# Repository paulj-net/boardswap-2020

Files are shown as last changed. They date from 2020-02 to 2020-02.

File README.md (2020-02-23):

# boardswap-2020

This repo contains design files for my contribution to the 2019/2020 boardswap series.  More details on our boardswap can be found on the Boldport Club Discord Server.

A little history on the project...  I got my start in electronics building guitar effects kits.  I've always been fascinated by audio and electronics.  This little circuit was orginally going to be a variation of an Atari Punk Console (hence some of the filenames) but it ended up just being a simple little one octave keyboard with a focus on correct pitch.  The circuit is tuned for proper note steps with the pot in the middle position.  Due to the type of circuit employed the steps between keys change as you move farther from the middle position.  It's not perfect, I'd change a few of the pads to make soldering easier.  I'd also spin the pot 180 degrees and experiment with other speakers.  The particular speaker chosen has a resonant frequency that is hit fairly easily as you play the instrument.  My kids love when that happens, I see it as an area for improvement.  In any case I hope you enjoy it!

Design files were all created in KiCad.

Mouser BOM is here:
https://www.mouser.com/ProjectManager/ProjectDetail.aspx?AccessID=b0c3233f29

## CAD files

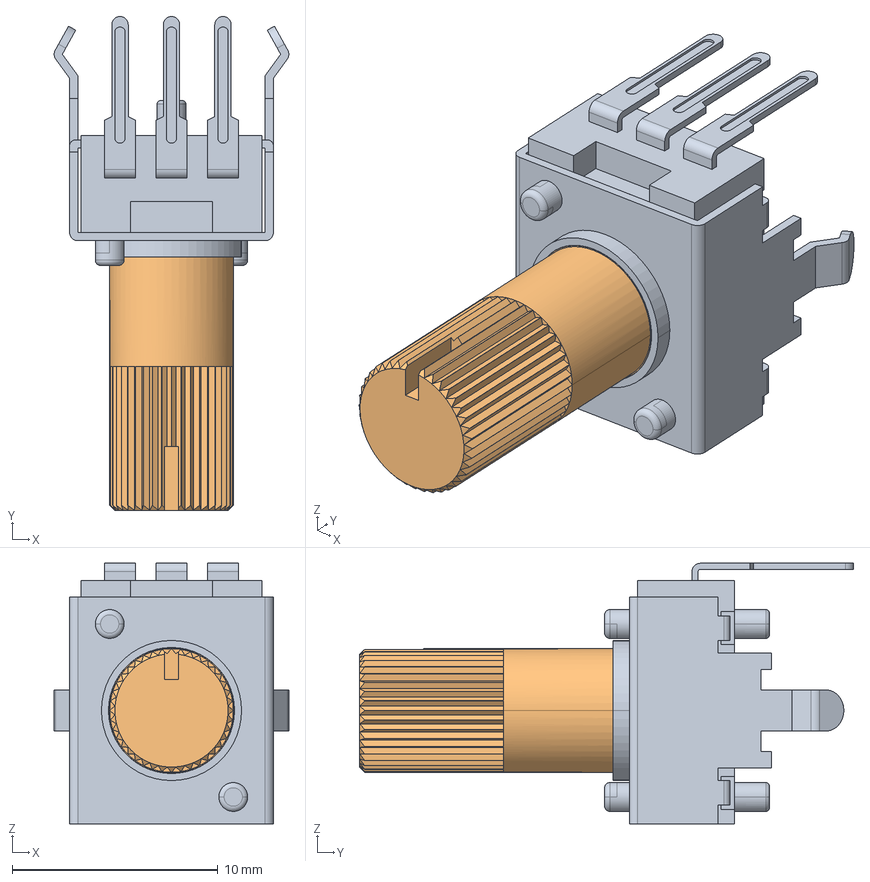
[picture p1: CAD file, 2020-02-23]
punk/parts/ptv09a-4x20u-xxxx.stp
11.4 x 24.0 x 12.7 mm

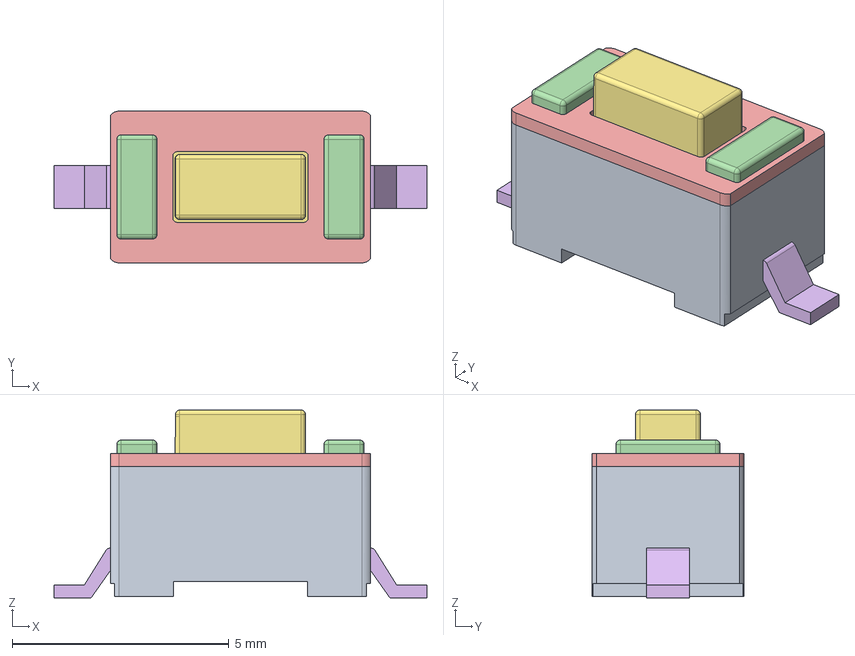
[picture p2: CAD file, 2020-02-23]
punk/parts/PTS636SM43SMTRLFS.stp
8.60 x 3.50 x 4.33 mm

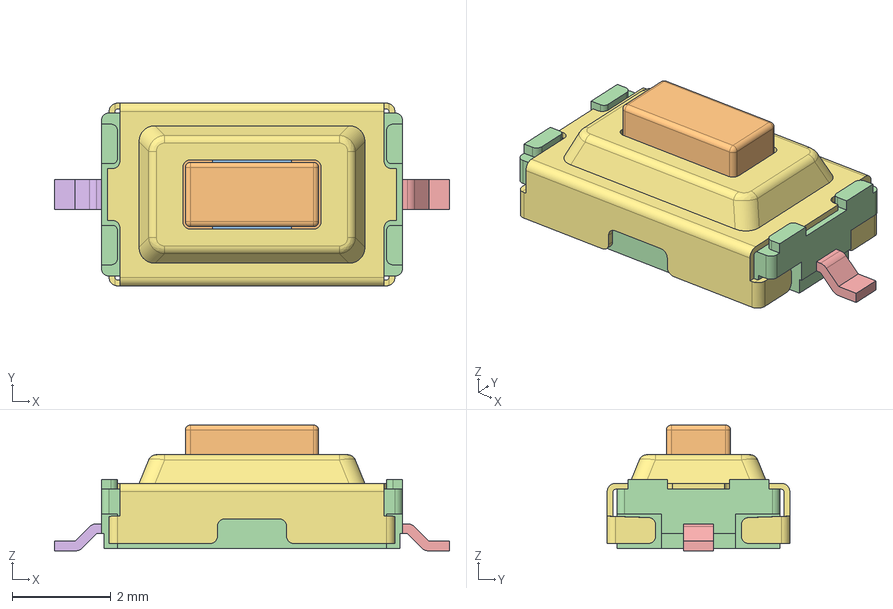
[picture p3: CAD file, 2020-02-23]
punk/parts/PTS636SM25SMTRLFS.stp
8.00 x 3.70 x 2.55 mm
MSBR-7_1
MSBR-6_1
MSBR-4_1
MSBR-3_1
MSBR-2_1
MSBR-1_1
MSBR-5-JIEDI_1

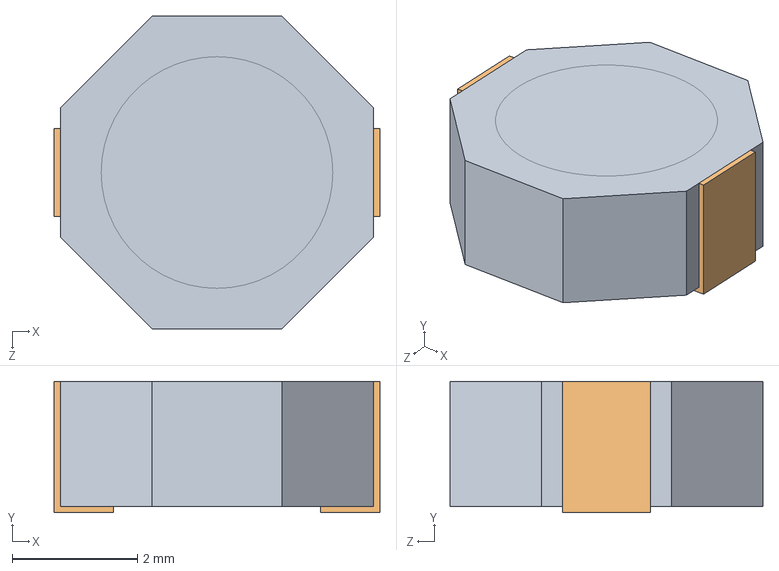
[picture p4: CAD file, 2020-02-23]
punk/parts/ltf5022-lc.step
5.20 x 2.10 x 5.00 mm
LTF5022-LC_素体
LTF5022-LC_端子 x 2

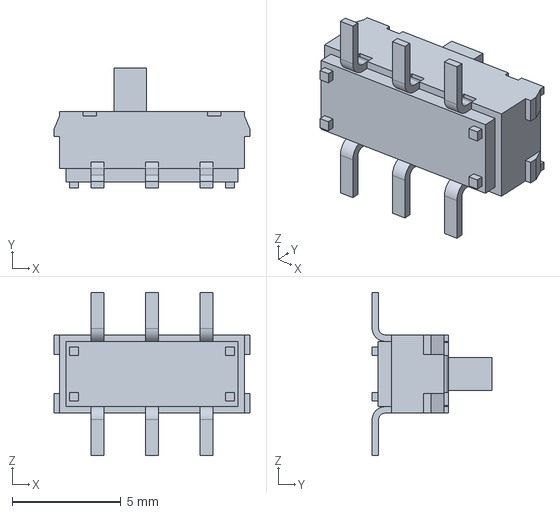
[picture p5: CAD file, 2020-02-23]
punk/parts/JS202011SCQN.stp
9.00 x 5.50 x 7.50 mm

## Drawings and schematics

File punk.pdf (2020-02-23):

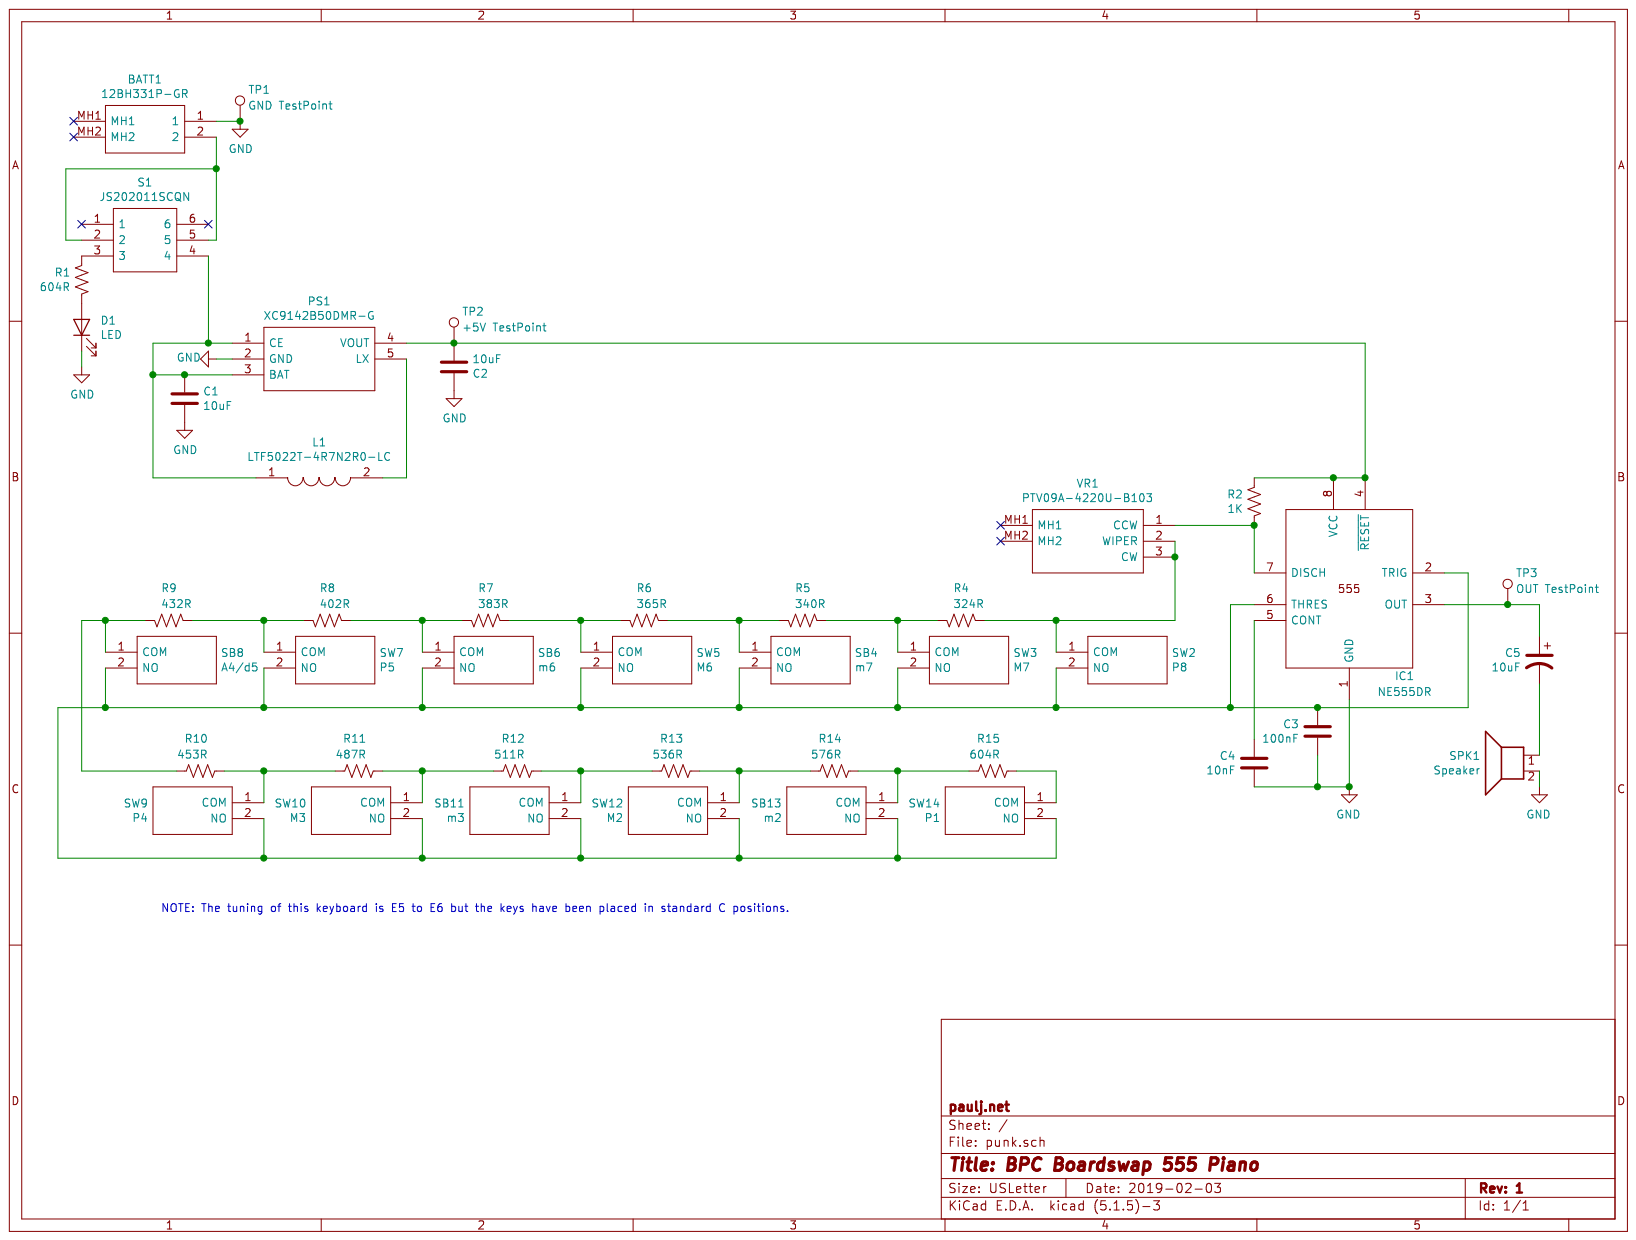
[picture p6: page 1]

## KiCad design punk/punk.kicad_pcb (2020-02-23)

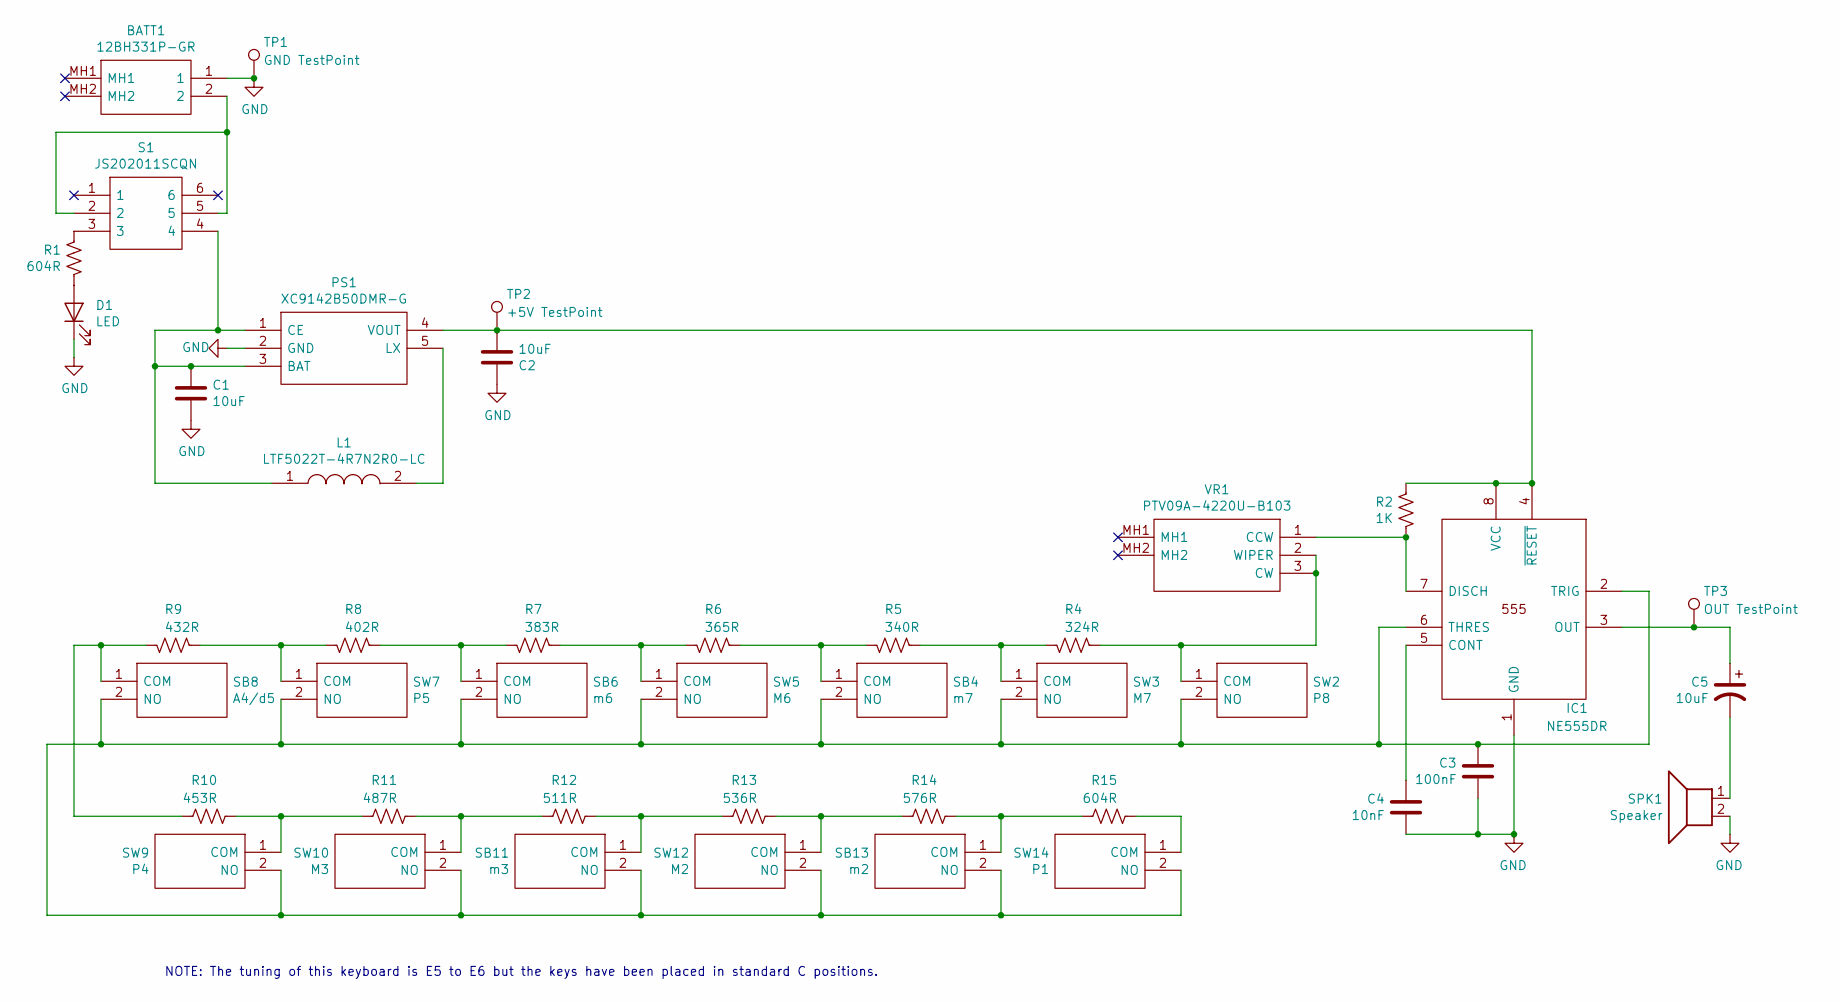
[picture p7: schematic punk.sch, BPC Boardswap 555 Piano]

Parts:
BATT1: 12BH331P-GR; 12BH331PGR; Mouser Part Number 12BH331P-GR
C1, C2: 10uF; C_0805_2012Metric_Pad1.15x1.40mm_HandSolder
C3: 100nF; C_0805_2012Metric_Pad1.15x1.40mm_HandSolder
C4: 10nF; C_0805_2012Metric_Pad1.15x1.40mm_HandSolder
C5: 10uF; CP_Elec_4x5.4
D1: LED; LED_1206_3216Metric_Pad1.42x1.75mm_HandSolder
IC1: NE555DR; SOIC127P600X175-8N; Mouser Part Number 595-NE555DR
L1: LTF5022T-4R7N2R0-LC; LTF5022; Mouser Part Number 810-LTF5022T4R7N2R0L
PS1: XC9142B50DMR-G; SOT95P280X120-5N; Mouser Part Number 865-XC9142B50DMR-G
R1, R15: 604R; R_0805_2012Metric_Pad1.15x1.40mm_HandSolder
R2: 1K; R_0805_2012Metric_Pad1.15x1.40mm_HandSolder
R4: 324R; R_0805_2012Metric_Pad1.15x1.40mm_HandSolder
R5: 340R; R_0805_2012Metric_Pad1.15x1.40mm_HandSolder
R6: 365R; R_0805_2012Metric_Pad1.15x1.40mm_HandSolder
R7: 383R; R_0805_2012Metric_Pad1.15x1.40mm_HandSolder
R8: 402R; R_0805_2012Metric_Pad1.15x1.40mm_HandSolder
R9: 432R; R_0805_2012Metric_Pad1.15x1.40mm_HandSolder
R10: 453R; R_0805_2012Metric_Pad1.15x1.40mm_HandSolder
R11: 487R; R_0805_2012Metric_Pad1.15x1.40mm_HandSolder
R12: 511R; R_0805_2012Metric_Pad1.15x1.40mm_HandSolder
R13: 536R; R_0805_2012Metric_Pad1.15x1.40mm_HandSolder
R14: 576R; R_0805_2012Metric_Pad1.15x1.40mm_HandSolder
S1: JS202011SCQN; Mouser Part Number 611-JS202011SCQN
SB4: m7; PTS636SM25SMTRLFS; Mouser Part Number 611-PTS636SM25SMTRLF
SB6: m6; PTS636SM25SMTRLFS; Mouser Part Number 611-PTS636SM25SMTRLF
SB8: A4/d5; PTS636SM25SMTRLFS; Mouser Part Number 611-PTS636SM25SMTRLF
SB11: m3; PTS636SM25SMTRLFS; Mouser Part Number 611-PTS636SM25SMTRLF
SB13: m2; PTS636SM25SMTRLFS; Mouser Part Number 611-PTS636SM25SMTRLF
SPK1: Speaker; TE2507051
SW2: P8; PTS636SM25SMTRLFS; Mouser Part Number 611-PTS636SM25SMTRLF
SW3: M7; PTS636SM25SMTRLFS; Mouser Part Number 611-PTS636SM25SMTRLF
SW5: M6; PTS636SM25SMTRLFS; Mouser Part Number 611-PTS636SM25SMTRLF
SW7: P5; PTS636SM25SMTRLFS; Mouser Part Number 611-PTS636SM25SMTRLF
SW9: P4; PTS636SM25SMTRLFS; Mouser Part Number 611-PTS636SM25SMTRLF
SW10: M3; PTS636SM25SMTRLFS; Mouser Part Number 611-PTS636SM25SMTRLF
SW12: M2; PTS636SM25SMTRLFS; Mouser Part Number 611-PTS636SM25SMTRLF
SW14: P1; PTS636SM25SMTRLFS; Mouser Part Number 611-PTS636SM25SMTRLF
TP1: GND TestPoint; TestPoint_THTPad_2.5x2.5mm_Drill1.2mm
TP2: +5V TestPoint; TestPoint_THTPad_2.5x2.5mm_Drill1.2mm
TP3: OUT TestPoint; TestPoint_THTPad_2.5x2.5mm_Drill1.2mm
VR1: PTV09A-4220U-B103; PTV09A-4#20

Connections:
GND: BATT1.1, C1.2, C2.1, C3.2, C4.2, D1.1 (K), IC1.1 (GND), PS1.2 (GND), SPK1.2, TP1.1; also elsewhere on the board
unnamed: BATT1.2, S1.2, S1.5
unnamed: C1.1, L1.1, PS1.1 (CE), PS1.3 (BAT), S1.4
unnamed 5: C2.2, IC1.4 (~RESET), IC1.8 (VCC), PS1.4 (VOUT), R2.1, TP2.1; also elsewhere on the board
unnamed: C3.1, IC1.2 (TRIG), IC1.6 (THRES), SB4.2 (NO), SB6.2 (NO), SB8.2 (NO), SB11.2 (NO), SB13.2 (NO), SW2.2 (NO), SW3.2 (NO), SW5.2 (NO), SW7.2 (NO), SW9.2 (NO), SW10.2 (NO), SW12.2 (NO), SW14.2 (NO)
unnamed: C4.1, IC1.5 (CONT)
unnamed 8: C5.1, IC1.3 (OUT), TP3.1; also elsewhere on the board
unnamed: C5.2, SPK1.1
unnamed: D1.2 (A), R1.2
unnamed: IC1.7 (DISCH), R2.2, VR1.1 (CCW)
unnamed: L1.2, PS1.5 (LX)
unnamed: R1.1, S1.3
unnamed: R4.1, SW2.1 (COM), VR1.2 (WIPER), VR1.3 (CW)
unnamed: R4.2, R5.1, SW3.1 (COM)
unnamed: R5.2, R6.1, SB4.1 (COM)
unnamed: R6.2, R7.1, SW5.1 (COM)
unnamed: R7.2, R8.1, SB6.1 (COM)
unnamed: R8.2, R9.1, SW7.1 (COM)
unnamed: R9.2, R10.1, SB8.1 (COM)
unnamed: R10.2, R11.1, SW9.1 (COM)
unnamed: R11.2, R12.1, SW10.1 (COM)
unnamed: R12.2, R13.1, SB11.1 (COM)
unnamed: R13.2, R14.1, SW12.1 (COM)
unnamed: R14.2, R15.1, SB13.1 (COM)
unnamed: R15.2, SW14.1 (COM)

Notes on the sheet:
NOTE: The tuning of this keyboard is E5 to E6 but the keys have been placed in standard C positions.

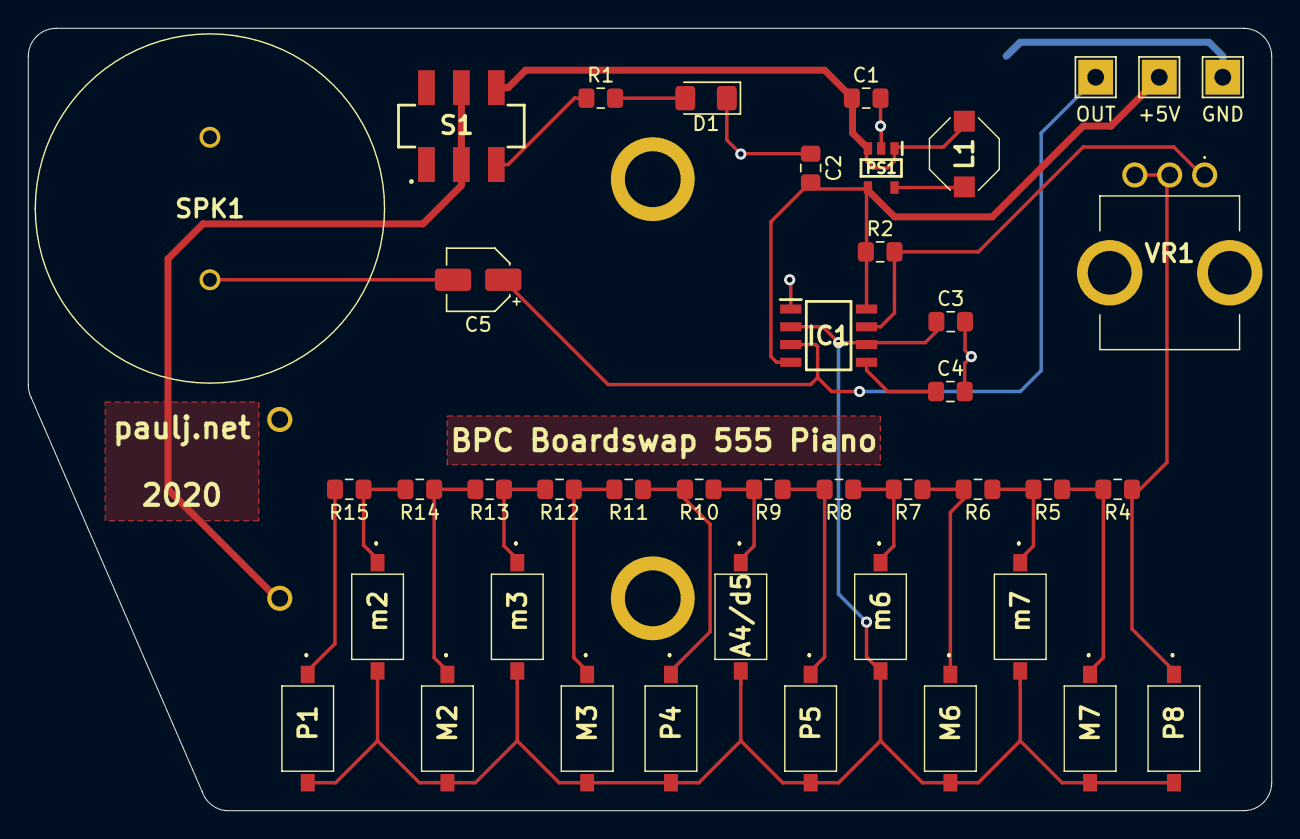
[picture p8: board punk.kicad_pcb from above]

Board: 2 copper layers, 89.0 x 56.0 mm, 43 parts (1 on the bottom side), 25 nets.

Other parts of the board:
+5V: +5V TestPoint; TestPoint_THTPad_2.5x2.5mm_Drill1.2mm
GND: GND TestPoint; TestPoint_THTPad_2.5x2.5mm_Drill1.2mm
OUT: OUT TestPoint; TestPoint_THTPad_2.5x2.5mm_Drill1.2mm

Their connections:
GND: GND.1; also elsewhere on the board
unnamed 5: +5V.1; also elsewhere on the board
unnamed 8: OUT.1; also elsewhere on the board
